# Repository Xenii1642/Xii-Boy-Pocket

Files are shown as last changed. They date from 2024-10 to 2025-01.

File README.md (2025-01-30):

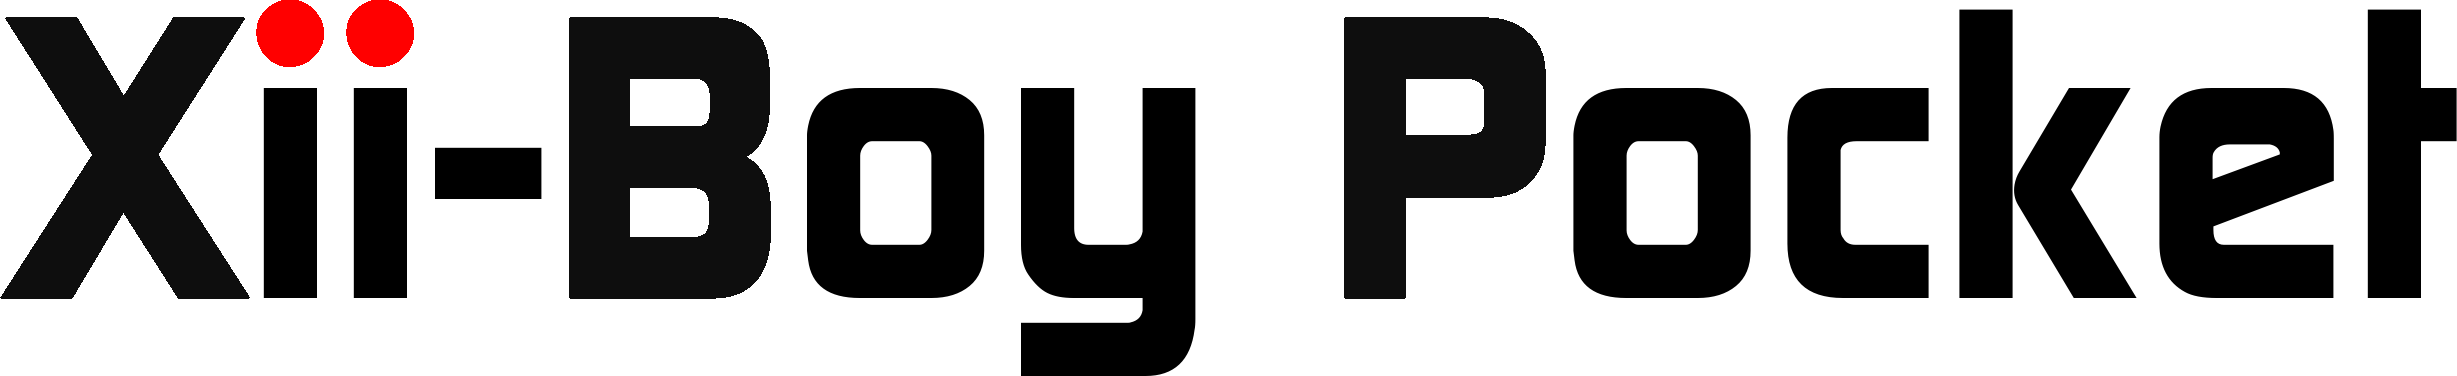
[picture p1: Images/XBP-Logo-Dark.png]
<picture> <source media="(prefers-color-scheme: dark)" srcset="Images/XBP-Logo-Light.png" width="800">  </picture> 

The Xii-Boy Pocket is a small portable Wii using a Game Boy form factor. The Xii-Boy Pocket is the second version of my Xii-Boy design.
This new portable Wii is now better, thinner, and above all, Open-Source ! Compared to the Gboy Rev III, it is 25% smaller and 5mm thinner !

If you want to learn more about it, you can check this BitBuilt Thread: [Xii-Boy Pocket's Thread](https://bitbuilt.net/forums/index.php?threads/the-xii-boy-pocket-v2.6638/)

If you want to see its development, you can check this BitBuilt Worklog: [Xii-Boy Pocket's Worklog](https://bitbuilt.net/forums/index.php?threads/xii-boy-v2-xeniis-second-portable-wii.6374/)

You can also learn more about the Xii-Boy Original here: [Xii-Boy Original Thread](https://bitbuilt.net/forums/index.php?threads/the-xii-boy-xeniis-first-portable-wii.6327/)

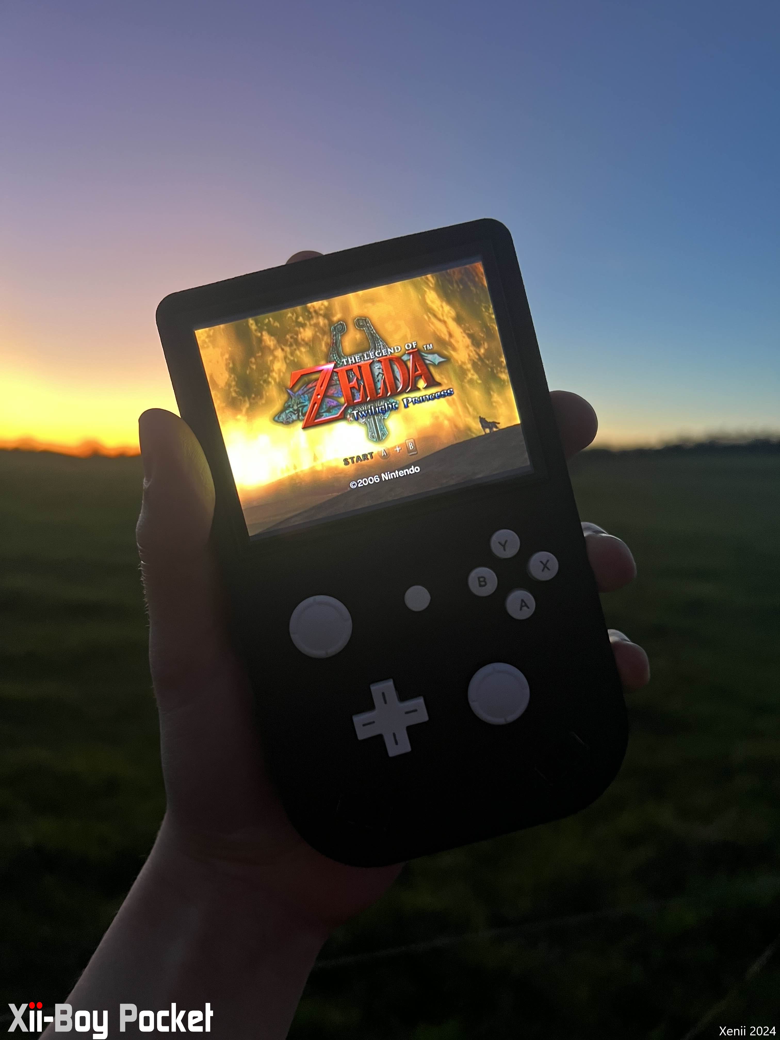
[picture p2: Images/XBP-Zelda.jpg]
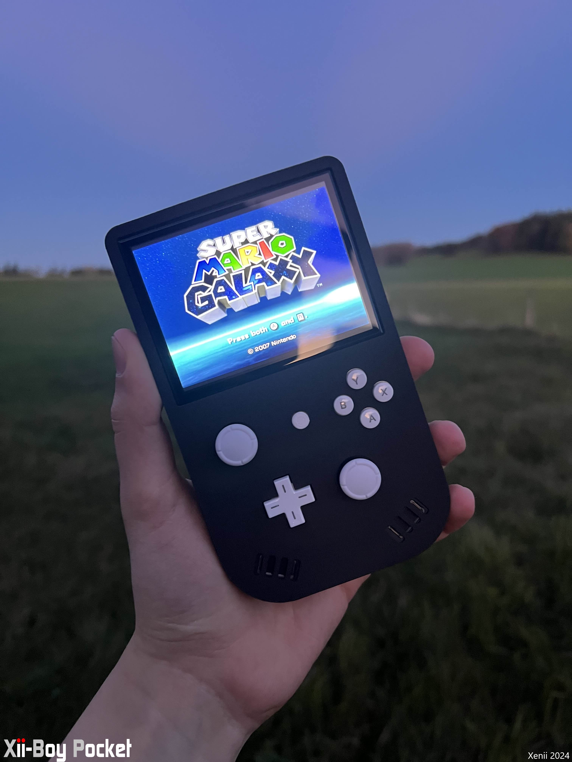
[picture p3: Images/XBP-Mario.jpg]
 
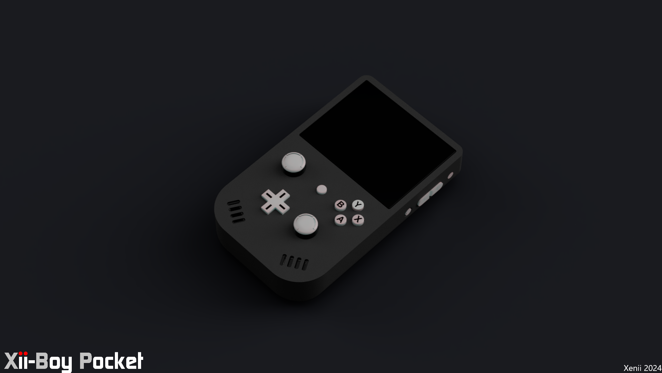
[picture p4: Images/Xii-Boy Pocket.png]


If you have any questions or problems about the Xii-Boy Pocket, please let me know 😉 Enjoy !

# Parts
All the parts you need to assemble a Xii-Boy Pocket are listed in the [Xii-Boy V2 Parts List.pdf](https://github.com/Xenii1642/Xii-Boy-Pocket/blob/main/Xii-Boy%20V2%20Parts%20List.pdf) file.

⚠ NOTE ⚠ For the batteries, I personally order mine through [Akkuteile](https://akkuteile.de/). However, if you don't live in Europe, you should buy your batteries somewhere else.
You just have to order two 18650 batteries. You shouldn't order them through Aliexpress, they could be fake and maybe dangerous

# PCB
All the Gerbers you need for the Xii-Boy Pocket are available in the [Gerber](https://github.com/Xenii1642/Xii-Boy-Pocket/tree/main/PCB%20Files/Gerber) folder.

All the needed components are listed in the [Xii-Boy V2 PCB BOM.pdf](https://github.com/Xenii1642/Xii-Boy-Pocket/blob/main/Xii-Boy%20V2%20PCB%20BOM.pdf) file.

The Xii-Boy Pocket's PCBs need specific settings to work properly:

### **Controller PCB**:
- ENIG surface finish 
  
### **Xii-Flex**:
- 0.12mm thickness
- Stiffener Polyimide 0.2 mm
  
### **Main PCB**:
- Impedance Controll YES
- Impedance Controll profile JLC04161H-7628

The other PCBs don't need specific settings. You can just let the setting by default 👍

I personally ordered mine through [JLCPCB](https://jlcpcb.com/) 👍

# Case
All the needed STLs are available in the [STL](https://github.com/Xenii1642/Xii-Boy-Pocket/tree/main/STL) folder.
If you want to order your case in **nylon** or **resin** through [JLC3DP](https://jlc3dp.com/), please use the case available in the [Case (JLC)](https://github.com/Xenii1642/Xii-Boy-Pocket/tree/main/STL/Case%20(JLC)) folder.

Otherwise, if you want to print / order it in FDM, use the case available in the [Case (FDM)](https://github.com/Xenii1642/Xii-Boy-Pocket/tree/main/STL/Case%20(FDM)) folder.

⚠️ Some of the buttons and fixations are too small to be manufactured by JLC3DP. To fix that, you can find a file which contains all the too small pieces [here](https://github.com/Xenii1642/Xii-Boy-Pocket/blob/main/STL/Buttons/Buttons-JLC.stl) ⚠️

I personally ordered my case through [JLC3DP](https://jlc3dp.com/) in **nylon SLS** and I printed the buttons in PLA 👍

⚠ NOTE ⚠ JLC3DP may ask you that there are some risks that the case could have warping or cracks. You have to accept them 👍

# STEP Files
You would like to make an edit on the case? No worries! You can find STEP files of the case in the [STEP folder](https://github.com/Xenii1642/Xii-Boy-Pocket/tree/main/STEP)

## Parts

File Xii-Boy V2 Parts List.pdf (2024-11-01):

Xii-Boy Pocket (V2) parts list

Parts | Quantity Link | Note

Controller
NDS Buttons | 1 https://www.aliexpress.com/item/1005006461579748.html | Buying NDS buttons and membranes from Aliexpress isn't the best choice.
NDS Membranes | 1 https://www.aliexpress.com/item/32832416623.html | If you can, you should take these from an original Nintendo DSi. The paint and the feeling will be better.
Switch Joysticks | 2 https://www.aliexpress.com/item/1005005499536700.html
Rumble Motor | 1 https://www.aliexpress.com/item/1005005616241057.html

Screen
Laminated 480p Screen | 1 https://www.aliexpress.com/item/1005006520627978.html | Select "With Black Cover"
480p Screen Driver Board | 1 https://www.aliexpress.com/item/1005003185913683.html | Select "HDMI Board"
Heatsink | | Select 50x100mm / 1mm 1pc
Fan | 1 https://www.aliexpress.com/item/4000313538245.html | Take "5V Balls 2PIN"
Heatsink | 1 https://www.aliexpress.com/item/1005005873687771.html
Copper Plate | 1 https://www.aliexpress.com/item/1005005993796912.html | Select 50x100mm / 1mm 1pc

Other
Batteries | 2 https://www.akkuteile.de/samsung-inr18650-35e-3-6v-3-7v-3500mah-pluspol-flach_100631_3391 If you don't live in Europe, you should buy your batteries somehwere else.
FFC Cables | 2 https://www.aliexpress.com/item/1005006653312883.html | You need 1x [60mm, Type A, 7P] and 1x [150, Type B, 10P]
Screews M1.7x4 | 39 https://www.aliexpress.com/item/33043885403.html | Select M1.7, 4mm, pan head
Screews M1.7x6 | 6 https://www.aliexpress.com/item/33043885403.html | Select M1.7 ,6mm, pan head
Speakers | 2 https://www.aliexpress.com/item/1005005931890295.html

PCB
LZ / RZ PCB | 1 https://github.com/Xenii1642/Xii-Boy-Pocket/tree/main/Gerber/RL-PCB
R / L PCB | 1 https://github.com/Xenii1642/Xii-Boy-Pocket/tree/main/Gerber/RL-PCB
Controller PCB | 1 https://github.com/Xenii1642/Xii-Boy-Pocket/tree/main/Gerber/Controller-PCB
Xii-Flex | 1 https://github.com/Xenii1642/Xii-Boy-Pocket/tree/main/Gerber/RL-PCB
Main PCB | 1 https://github.com/Xenii1642/Xii-Boy-Pocket/tree/main/Gerber/Main-PCB
RVL-PMS | 1 https://github.com/Gmanmodz/RVL-Power-Management-System

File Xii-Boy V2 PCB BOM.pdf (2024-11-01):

Xii-Boy V2 PCB BOM

LZ / RZ PCB
Reference | Quantity Description | Manufacter Product Number | Link
B1, B2 | 2 SWITCH TACTILE SPST-NO 0.05A 15V | TL3315NF250Q | https://www.digikey.com/en/products/detail/e-switch/TL3315NF250Q/1870396

L / R PCB
Reference | Quantity Description | Manufacter Product Number | Link
B1, B2 | 2 Dual Tact Button | TMHF07 | https://www.aliexpress.com/item/33003093225.html
P1 | 1 CONN FFC BOTTOM 7POS 0.5MM R/A | 5051100792 | https://www.digikey.com/en/products/detail/molex/5051100792/5700455

Controller PCB
Reference | Quantity Description | Manufacter Product Number | Link
B1 | 1 SWITCH TACTILE SPST-NO 0.05A 15V | TL3315NF250Q | https://www.digikey.com/en/products/detail/e-switch/TL3315NF250Q/1870396
C1, C2, C3 | 3 CAP CER 0.1UF 16V X7R 0402 | GRM155R71C104KA88J | https://www.digikey.com/en/products/detail/murata-electronics/GRM155R71C104KA88J/2610892
D1 | 1 DIODE ARR SCHOTT 20V TO236AB | PMEG2005CT,215 | https://www.digikey.com/en/products/detail/nexperia-usa-inc/PMEG2005CT-215/2119859
P1 | 1 CONN FFC BOTTOM 10POS 0.5MM R/A | 5051101092 | https://www.digikey.com/en/products/detail/molex/5051101092/5700458
P2 | 1 CONN FFC BOTTOM 7POS 0.5MM R/A | 5051100792 | https://www.digikey.com/en/products/detail/molex/5051100792/5700455
P3, P4 | 2 CONN FFC BOTTOM 5POS 0.5MM R/A | 5051100592 | https://www.digikey.com/en/products/detail/molex/5051100592/5700453
R1, R2 | 2 RES 10K OHM 5% 1/16W 0402 | RC0402JR-0710KL | https://www.digikey.com/en/products/detail/yageo/RC0402JR-0710KL/726418
R3 | 1 RES 100 OHM 1% 1/16W 0402 | RC0402FR-07100RL | https://www.digikey.com/en/products/detail/yageo/RC0402FR-07100RL/726527
U1 | 1 IC MCU 8BIT 32KB FLASH 28QFN | PIC18F25K42T-I/ML | https://www.digikey.com/en/products/detail/microchip-technology/PIC18F25K42T-I-ML/6685387
U2 | 1 IC MOTOR DRIVER 2.5V-5.2V 10QFN | DRV2603RUNR | https://www.digikey.com/en/products/detail/texas-instruments/DRV2603RUNR/3487230

Main PCB
Reference | Quantity Description | Manufacter Product Number | Link
B1, B2, B3, B4 | 4 SWITCH TACTILE SPST-NO 0.05A 12V | TL3336AF160Q | https://www.digikey.com/en/products/detail/e-switch/TL3336AF160Q/14123602
C1, C2, C3, C12, C15 | 5 CAP CER 1UF 6.3V X5R 0402 | CL05A105MQ5NNNC | https://www.digikey.com/en/products/detail/samsung-electro-mechanics/CL05A105MQ5NNNC/3886893
C4 | 1 CAP CER 10UF 6.3V X5R 0402 | GRM155R60J106ME05D | https://www.digikey.com/en/products/detail/murata-electronics/GRM155R60J106ME05D/11500166
C5, C6, C7, C8, C9, C10, C11 | 7 CAP CER 2.2UF 6.3V X5R 0402 | CL05A225MQ5NNNC | https://www.digikey.com/en/products/detail/samsung-electro-mechanics/CL05A225MQ5NNNC/3887127
C13, C14 | 2 CAP CER 4.7UF 6.3V X5R 0402 | GRM155R60J475ME87J | https://www.digikey.com/en/products/detail/murata-electronics/GRM155R60J475ME87J/9867919
LED1 | 1 LED RGB 0606 SMD | B38G3RGB-10D0003H2U1930 | https://www.digikey.com/en/products/detail/harvatek-corporation/B38G3RGB-10D0003H2U1930/13588733
P1 | 1 CONN RCPT TYPE C 6P SMD RA | USB4125-GF-A | https://www.digikey.com/en/products/detail/gct/USB4125-GF-A/13547388
P2 | 1 CONN FFC BOTTOM 10POS 0.5MM R/A | 5051101092 | https://www.digikey.com/en/products/detail/molex/5051101092/5700458
P3 | 1 MICRO SD PUSH/PUSH SMALL 8C | 5033981892 | https://www.digikey.com/en/products/detail/molex/5033981892/4555393
P4 | 1 CONN FFC BOTTOM 17POS 0.5MM R/A | 5051101792 | https://www.digikey.com/en/products/detail/molex/5051101792/5700465
P5 | 1 CONN RCPT 16POS SMD GOLD | 541020164 | https://www.digikey.com/en/products/detail/molex/0541020164/3197036
P6 | 1 CONN RCPT 20POS SMD GOLD | 529910208 | https://www.digikey.com/en/products/detail/molex/0529910208/1059850
P7 | 1 CONN JACK STEREO 3.5MM SMD R/A | SJ-3524-SMT-TR | https://www.digikey.com/en/products/detail/cui-devices/SJ-3524-SMT-TR/281298
R1, R2, R4 | 3 RES 10K OHM 5% 1/16W 0402 | RC0402JR-0710KL | https://www.digikey.com/en/products/detail/yageo/RC0402JR-0710KL/726418
R3 | 1 RES 24K OHM 1% 1/16W 0402 | WR04X2402FTL | https://www.digikey.com/en/products/detail/walsin-technology-corporation/WR04X2402FTL/16569971
R5 | 1 RES 1K OHM 1% 1/16W 0402 | WR04X1001FTL | https://www.digikey.com/en/products/detail/walsin-technology-corporation/WR04X1001FTL/13240628
U1 | 1 IC MCU 8BIT 7KB FLASH 16UQFN | PIC16LF15324-I/JQ | https://www.digikey.com/en/products/detail/microchip-technology/PIC16LF15324-I-JQ/6691288
U2 | 1 IC REG LINEAR 2.5V 250MA SOT23-5 | LP5907MFX-2.5/NOPB | https://www.digikey.com/en/products/detail/texas-instruments/LP5907MFX-2-5-NOPB/5019039
U3 | 1 IC AMP CLASS D STER 2.5W 32WQFN | LM49450SQ/NOPB | https://www.digikey.com/en/products/detail/texas-instruments/LM49450SQ-NOPB/1871761
U4 | 1 CH224K USB PD Protocol Sink Chip IC | CH224K | https://www.aliexpress.com/item/1005005284290184.html
U5 | 1 GL823K GL823 SSOP-16 | GL823K | https://www.aliexpress.com/item/1005007494983714.html

RVL-PMS (Gman)
Reference | Quantity Description | Manufacter Product Number | Link
U1 U2 U3 U4 | 4 IC REG BUCK ADJUSTABLE 4A 16VQFN | TLV62095RGTR | https://www.digikey.com/product-detail/en/texas-instruments/TLV62095RGTR/296-46277-1-ND/7033452
U5 | 1 IC REG BOOST 5V 4A 10VSON | TPS61232DRCR | https://www.digikey.com/product-detail/en/texas-instruments/TPS61232DRCR/296-44498-1-ND/6110782
U6 | 1 IC MCU 8BIT 7KB FLASH 16UQFN | PIC16F15324T-I/JQ | https://www.digikey.com/product-detail/en/microchip-technology/PIC16F15324T-I-JQ/PIC16F15324T-I-JQCT-ND/7346310
U7 | 1 IC NVDC CHARGER I2C 24WQFN | BQ25895MRTWR | https://www.digikey.com/en/products/detail/texas-instruments/BQ25895MRTWR/5413643
R1 | 1 RES SMD 44.2K OHM 1% 1/10W 0603 | RC0603FR-0744K2L | https://www.digikey.com/product-detail/en/yageo/RC0603FR-0744K2L/311-44.2KHRCT-ND/730188
R2 R4 R6 R8 | 4 RES SMD 160K OHM 1% 1/10W 0603 | RC0603FR-07160KL | https://www.digikey.com/product-detail/en/yageo/RC0603FR-07160KL/311-160KHRCT-ND/729920
R3 | 1 RES SMD 75K OHM 1% 1/10W 0603 | RC0603FR-0775KL | https://www.digikey.com/product-detail/en/yageo/RC0603FR-0775KL/311-75.0KHRCT-ND/730325
R5 | 1 RES SMD 200K OHM 1% 1/10W 0603 | RC0603FR-07200KL | https://www.digikey.com/product-detail/en/yageo/RC0603FR-07200KL/311-200KHRCT-ND/729991
R7 | 1 RES SMD 510K OHM 1% 1/10W 0603 | RC0603FR-07510KL | https://www.digikey.com/product-detail/en/yageo/RC0603FR-07510KL/311-510KHRCT-ND/730233
R9 R10 R11 | 3 RES 1.2K OHM 1% 1/10W 0603 | RMCF0603FT1K20 | https://www.digikey.com/product-detail/en/stackpole-electronics-inc/RMCF0603FT1K20/RMCF0603FT1K20CT-ND/1942999
R12 R13 R17 R18 | 4 RES SMD 10K OHM 1% 1/10W 0603 | RC0603FR-0710KL | https://www.digikey.com/product-detail/en/yageo/RC0603FR-0710KL/311-10.0KHRCT-ND/729827
R14 | 1 RES SMD 261 OHM 1% 1/10W 0603 | RC0603FR-07261RL | https://www.digikey.com/product-detail/en/yageo/RC0603FR-07261RL/311-261HRCT-ND/730042
R15 R16 | 2 RES SMD 4.7K OHM 1% 1/10W 0603 | RC0603FR-074K7L | https://www.digikey.com/product-detail/en/yageo/RC0603FR-074K7L/311-4.70KHRCT-ND/730159
C1 C3 C5 C7 C9 C10 C11 C12 C13, C14,
C15, C16, C17, C18, C19, C20
C14 C15 C16 C17 C18 C19 C20 | 16 CAP CER 22UF 6.3V X5R 0805 | CL21A226MQQNNNE | https://www.digikey.com/product-detail/en/samsung-electro-mechanics/CL21A226MQQNNNE/1276-1100-1-ND/3889186
C2 C4 C6 C8 | 4 CAP CER 10000PF 50V X7R 0603 | 06035C103KAT4A | https://www.digikey.com/product-detail/en/avx-corporation/06035C103KAT4A/478-10055-1-ND/6564278
C21 | 1 CAP CER 1UF 25V X7R 0805 | GCM21BR71E105KA56L | https://www.digikey.com/product-detail/en/murata-electronics-north-america/GCM21BR71E105KA56L/490-4785-1-ND/1641704
C22 | 1 CAP CER 0.1UF 25V X5R 0603 | CL10A104KA8NNNC | https://www.digikey.com/product-detail/en/samsung-electro-mechanics/CL10A104KA8NNNC/1276-1857-1-ND/3889943
C23 | 1 CAP CER 0.047UF 25V X7R 0603 | C0603C473K3RACTU | https://www.digikey.com/product-detail/en/kemet/C0603C473K3RACTU/399-7931-1-ND/3471654
C24 C26 C27 C28 | 4 CAP CER 10UF 16V X5R 0805 | CL21A106KOQNNNG | https://www.digikey.com/product-detail/en/samsung-electro-mechanics/CL21A106KOQNNNG/1276-6455-1-ND/5958083
C25 | 1 CAP CER 4.7UF 16V X5R 0603 | CL10A475KO8NNNC | https://www.digikey.com/product-detail/en/samsung-electro-mechanics/CL10A475KO8NNNC/1276-1784-1-ND/3889870
L1 L2 L3 L4 L5 | 5 FIXED IND 1UH 5.1A 27 MOHM SMD | MDWK4040T1R0MM | https://www.digikey.com/product-detail/en/taiyo-yuden/MDWK4040T1R0MM/587-4447-1-ND/5880037
L6 | 1 FIXED IND 2.2UH 8A 20 MOHM SMD | ASPI-0630HI-2R2M-T15 | https://www.digikey.com/product-detail/en/abracon-llc/ASPI-0630HI-2R2M-T15/ASPI-0630HI-2R2M-T15CT-ND/3060148

Screen Driver Board
Reference | Quantity Description | Manufacter Product Number | Link
Crystal (Y1) | 1 CRYSTAL 27.0000MHZ 8PF SMD | LNCD1-27M | https://www.digikey.com/en/products/detail/ndk-america-inc/LNCD1-27M/1128824
Inductor (L14) | 1 FIXED IND 22UH 450MA 910MOHM SMD | 74404024220 | https://www.digikey.com/en/products/detail/w%C3%BCrth-elektronik/74404024220/4865382

Other
Name | Quantity Description | Manufacter Product Number | Link
Wifi Antenna | 2 RF ANT 2.45GHZ PCB TRACE CAB ADH | ANTX100P011B24003 | https://www.digikey.com/en/products/detail/pulse-electronics/ANTX100P011B24003/9360397
Battery Clips | 4 BATT CONT SPR MULTI SOLDER LUG | 1107-1 | https://www.digikey.com/en/products/detail/keystone-electronics/1107-1/5056817
Thermistor | 1 THERMISTOR NTC 10KOHM 3470K BEAD | MF52A2103J3470 | https://www.digikey.com/en/products/detail/cantherm/MF52A2103J3470/1191033
Light Pipe | 1 LIGHT PIPE PNL 3MM DFF FLAT.100" | PLP1-100-FD | https://www.digikey.com/en/products/detail/bivar-inc/PLP1-100-F-D/5721997

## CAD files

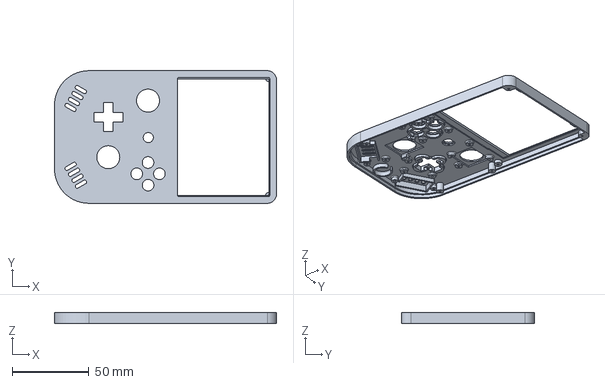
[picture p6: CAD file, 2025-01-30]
STEP/JLC/Xii-Boy Pocket Top (JLC).step
145.0 x 86.7 x 7.50 mm

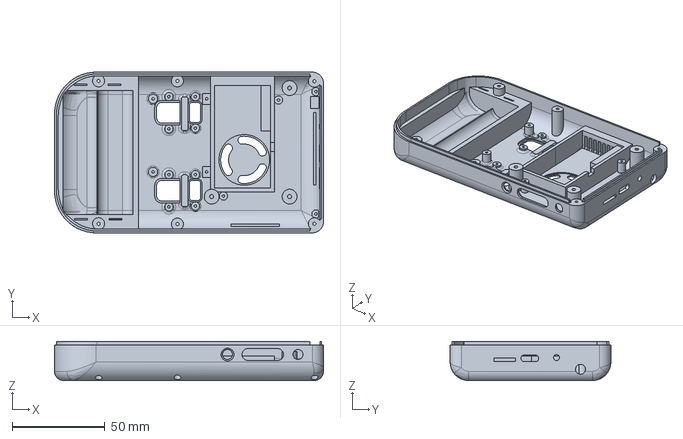
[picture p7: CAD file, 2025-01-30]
STEP/Xii-Boy Pocket Bottom.step
145.0 x 86.6 x 21.1 mm

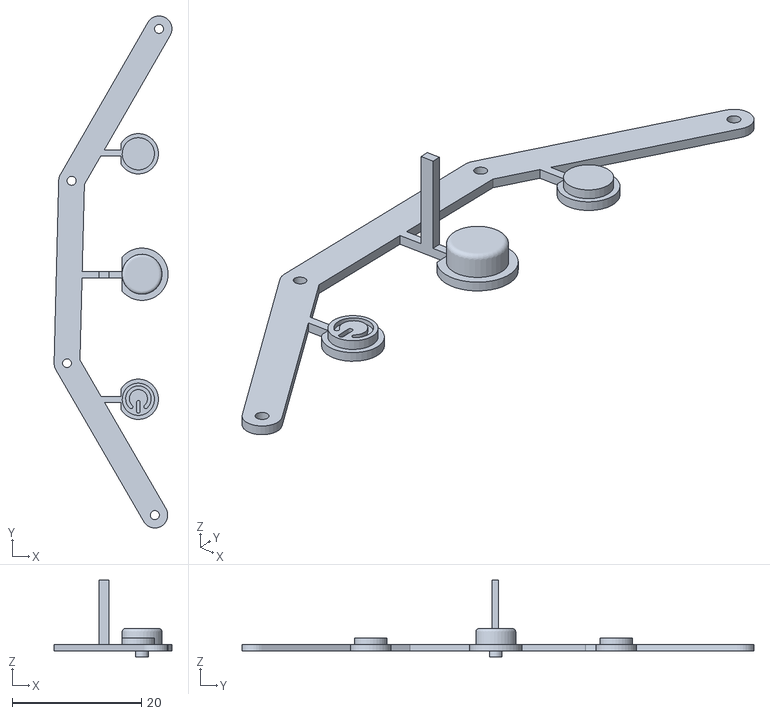
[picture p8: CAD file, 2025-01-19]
STL/Buttons/Buttons-JLC.stl
18.2 x 79.3 x 11.9

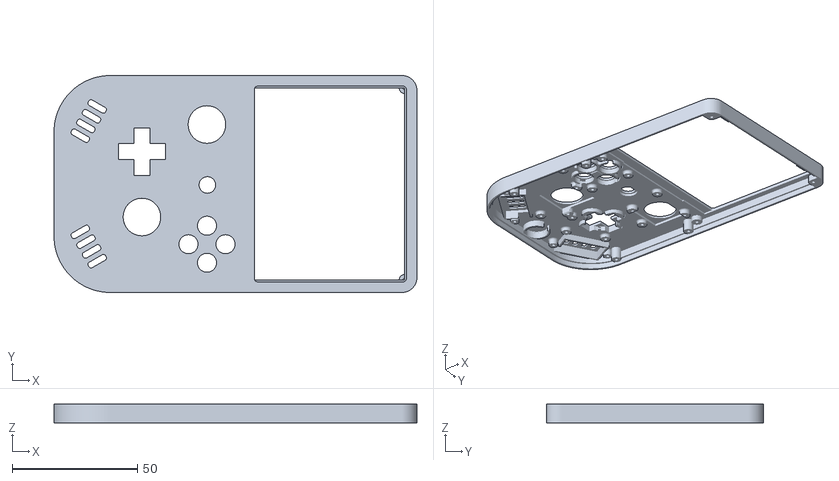
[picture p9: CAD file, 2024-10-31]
STL/Case (FDM)/Xii-Boy Top.stl
145.0 x 86.6 x 7.50

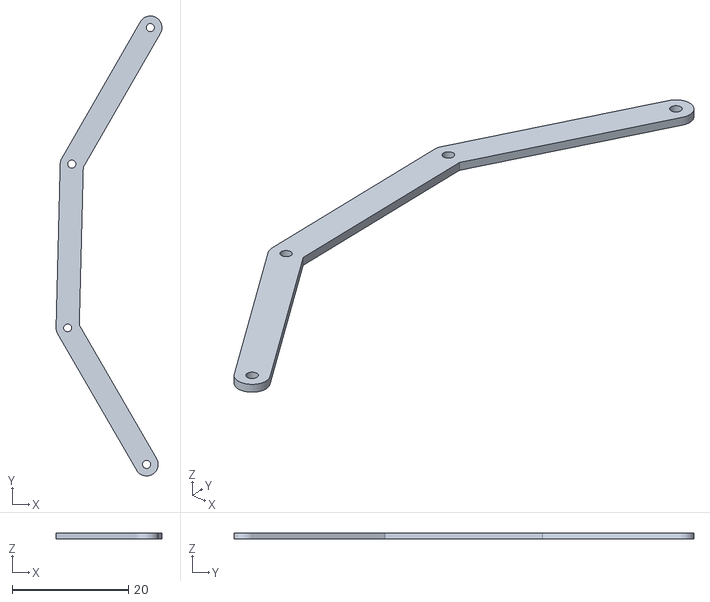
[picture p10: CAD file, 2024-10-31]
STL/Fixations/Speakers + Rumble.stl
18.3 x 79.3 x 1.00

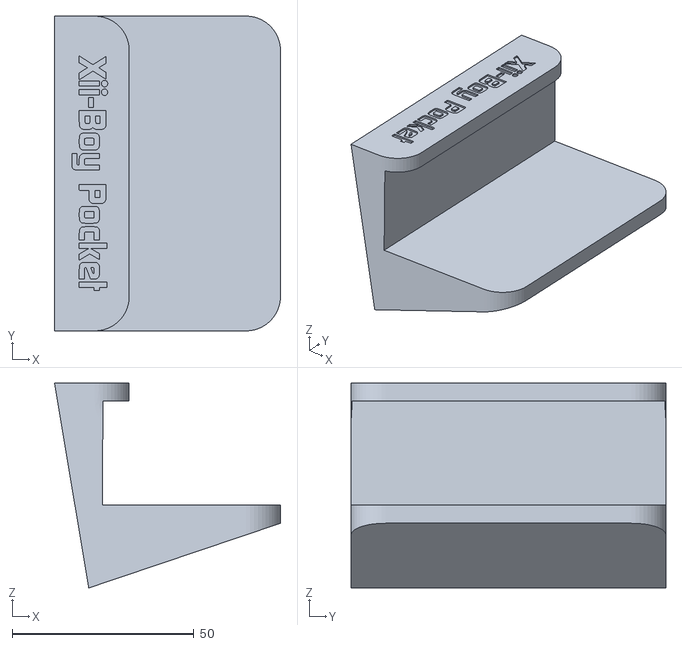
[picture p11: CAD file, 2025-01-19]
STL/Xii-Boy Pocket Stand (without XiiSBar).stl
62.2 x 86.6 x 56.4

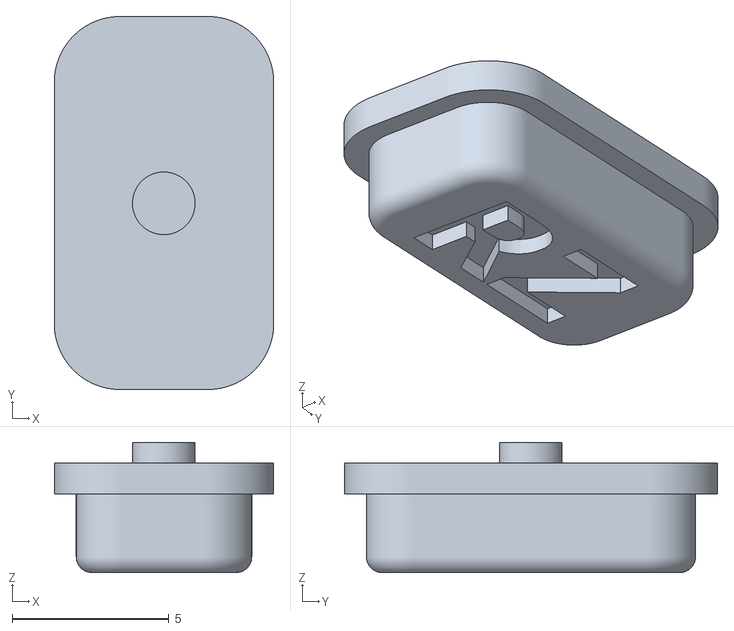
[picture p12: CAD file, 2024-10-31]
STL/Buttons/RZ.stl
7.00 x 11.9 x 4.15

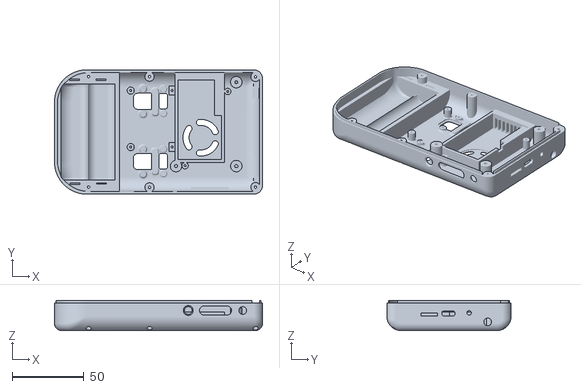
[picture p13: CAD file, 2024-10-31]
STL/Case (FDM)/Xii-Boy Bottom.stl
145.0 x 86.6 x 21.1

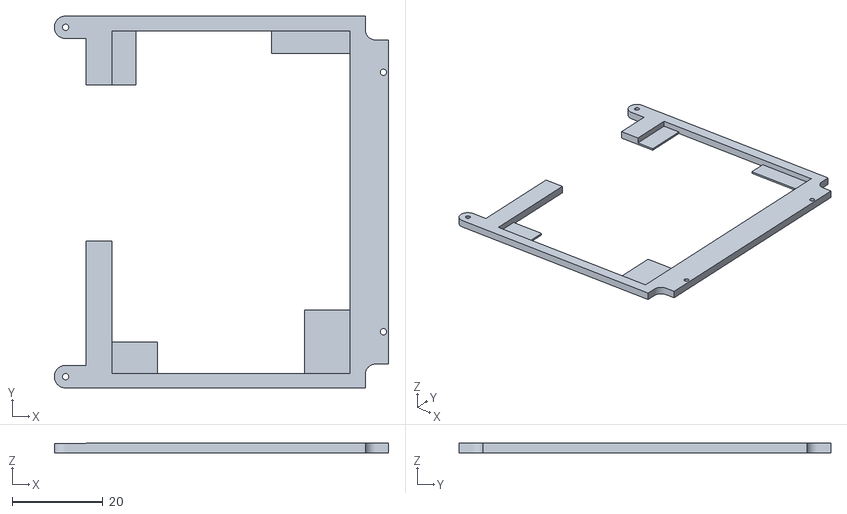
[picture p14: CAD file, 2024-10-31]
STL/Fixations/Driver Board.stl
73.9 x 82.2 x 2.10

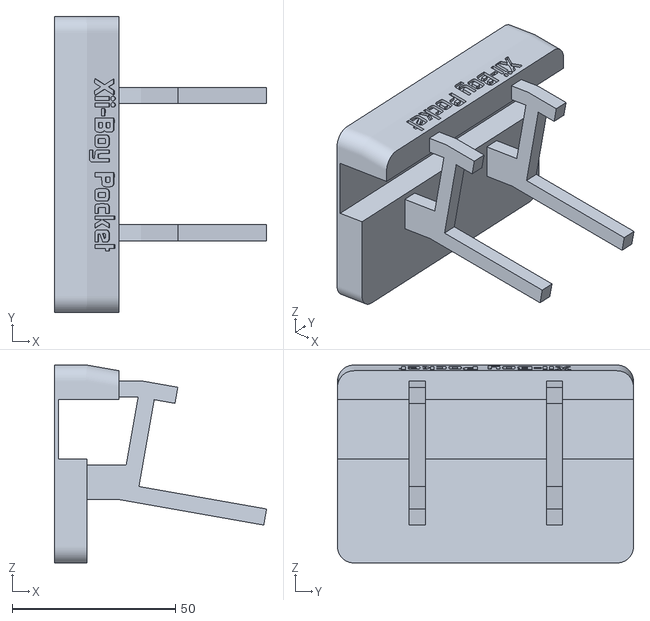
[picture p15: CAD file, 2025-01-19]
STL/Xii-Boy Pocket Stand.stl
65.0 x 90.6 x 60.6

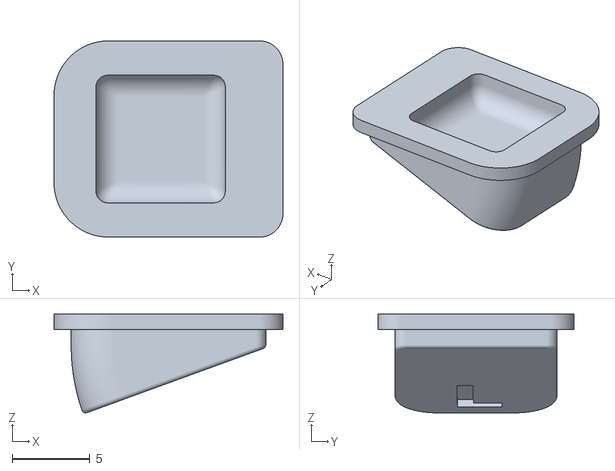
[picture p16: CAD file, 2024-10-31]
STL/Buttons/L.stl
14.7 x 12.6 x 6.34

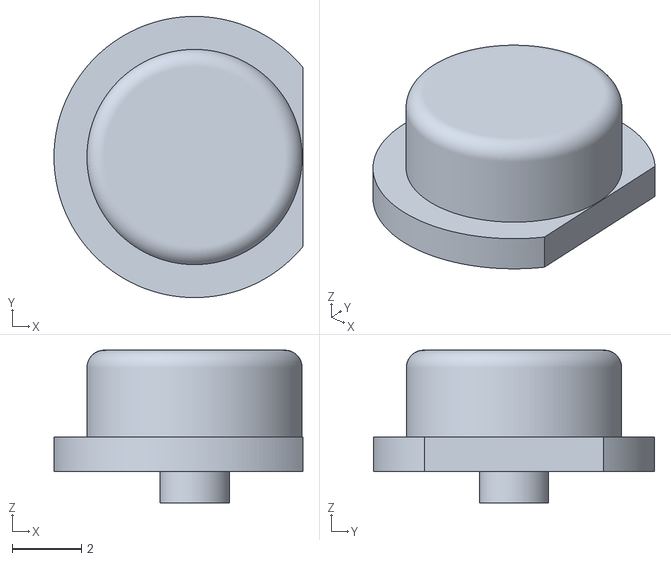
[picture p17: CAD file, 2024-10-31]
STL/Buttons/Start.stl
7.17 x 8.10 x 4.40

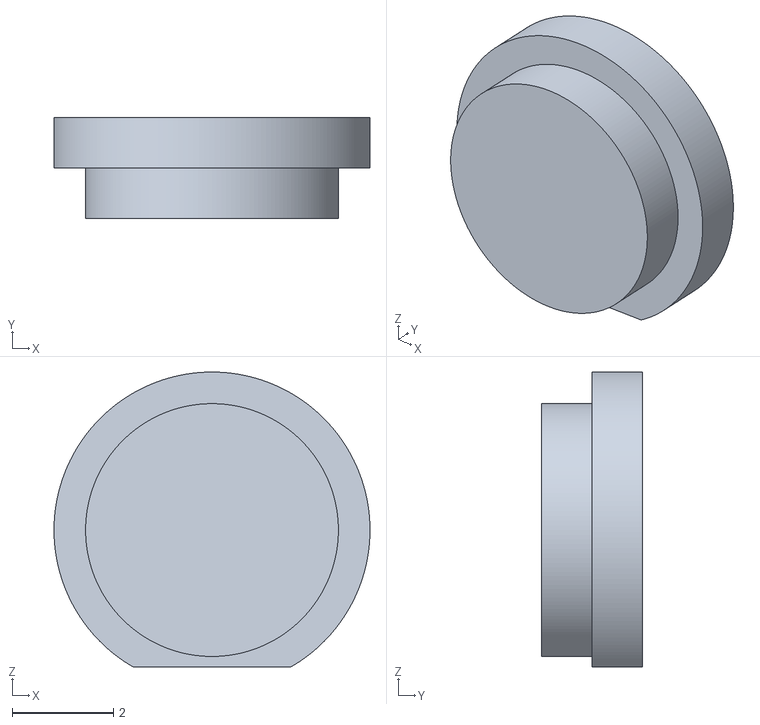
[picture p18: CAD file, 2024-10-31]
STL/Buttons/Sync.stl
6.25 x 2.00 x 5.83

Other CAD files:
STL/Case (JLC)/Xii-Boy Top (JLC).stl
STEP/JLC/Xii-Boy Pocket Bottom (JLC).step
STEP/Xii-Boy Pocket Top.step
STL/Case (JLC)/Xii-Boy Bottom (JLC).stl
STL/Buttons/LZ.stl
STL/Buttons/Power.stl
STL/Buttons/R.stl
STL/Buttons/Volume.stl

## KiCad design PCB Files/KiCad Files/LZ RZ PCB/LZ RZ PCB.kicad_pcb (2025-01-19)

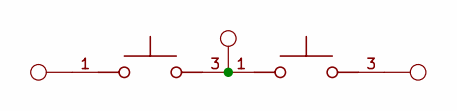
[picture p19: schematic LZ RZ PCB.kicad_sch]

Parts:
S1, S2: TL3315NF250Q; SW_TL3315NF250Q
TP1: LZ; TestPoint_Pad_D1.0mm
TP2: GND; TestPoint_Pad_D1.0mm
TP3: RZ; TestPoint_Pad_D1.0mm

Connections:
unnamed: S1.1, TP1.1
unnamed: S1.3, S2.1, TP2.1
unnamed: S2.3, TP3.1

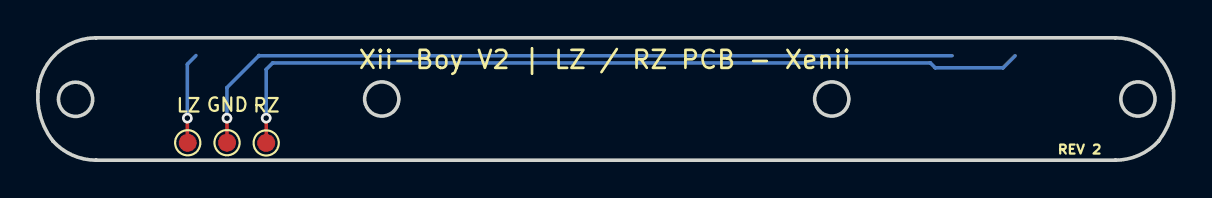
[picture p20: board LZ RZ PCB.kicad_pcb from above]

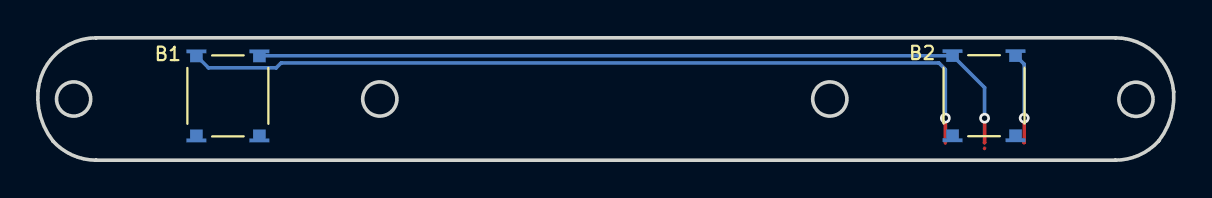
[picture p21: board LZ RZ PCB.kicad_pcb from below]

Board: 2 copper layers, 63.1 x 6.8 mm, 5 parts (2 on the bottom side), 3 nets.

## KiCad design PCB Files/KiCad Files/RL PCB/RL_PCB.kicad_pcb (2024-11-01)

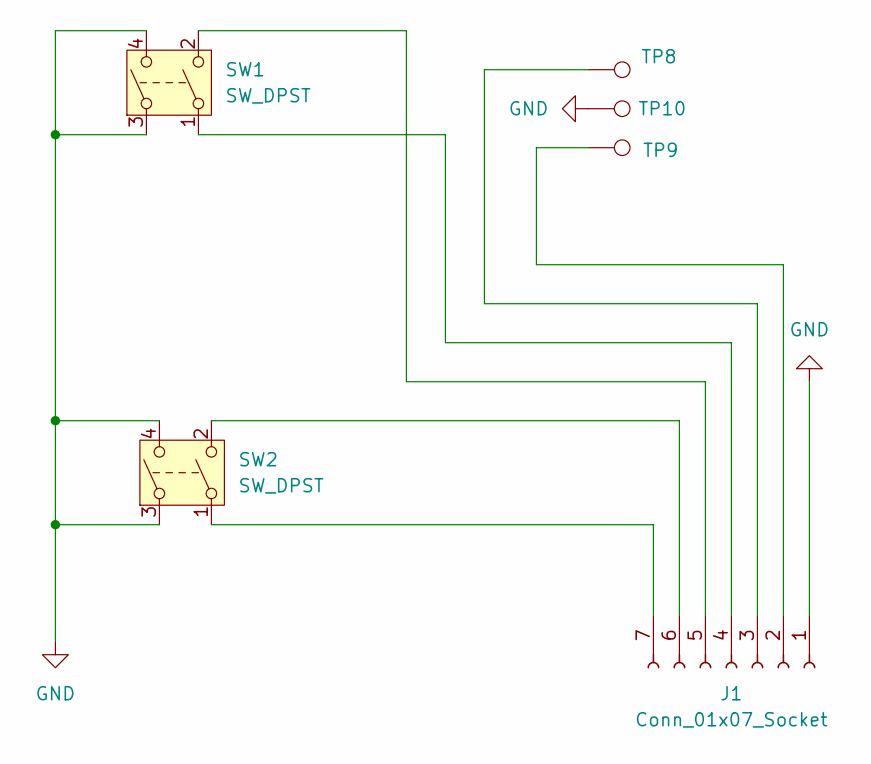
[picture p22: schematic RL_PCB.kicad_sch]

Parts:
J1: Conn_01x07_Socket; CON_5051100792_MOL
SW1, SW2: SW_DPST; TMHF07
TP8, TP9, TP10: TestPoint; TestPoint_Pad_D1.0mm

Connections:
GND: J1.1, SW1.3, SW1.4, SW2.3, SW2.4, TP10.1
unnamed: J1.2, TP9.1
unnamed: J1.3, TP8.1
unnamed: J1.4, SW1.1
unnamed: J1.5, SW1.2
unnamed: J1.6, SW2.2
unnamed: J1.7, SW2.1

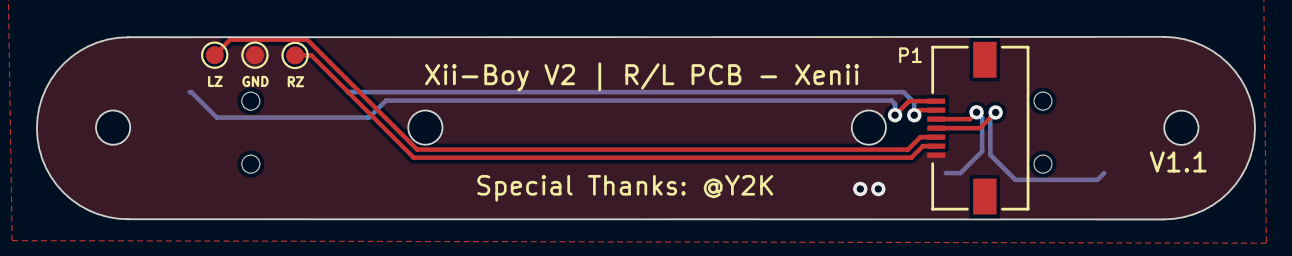
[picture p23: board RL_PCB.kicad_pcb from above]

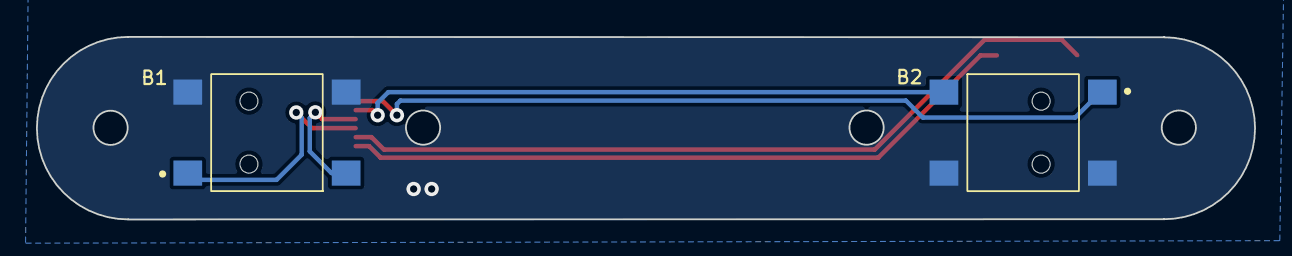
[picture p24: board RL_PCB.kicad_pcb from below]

Board: 2 copper layers, 67.7 x 10.1 mm, 6 parts (2 on the bottom side), 7 nets.

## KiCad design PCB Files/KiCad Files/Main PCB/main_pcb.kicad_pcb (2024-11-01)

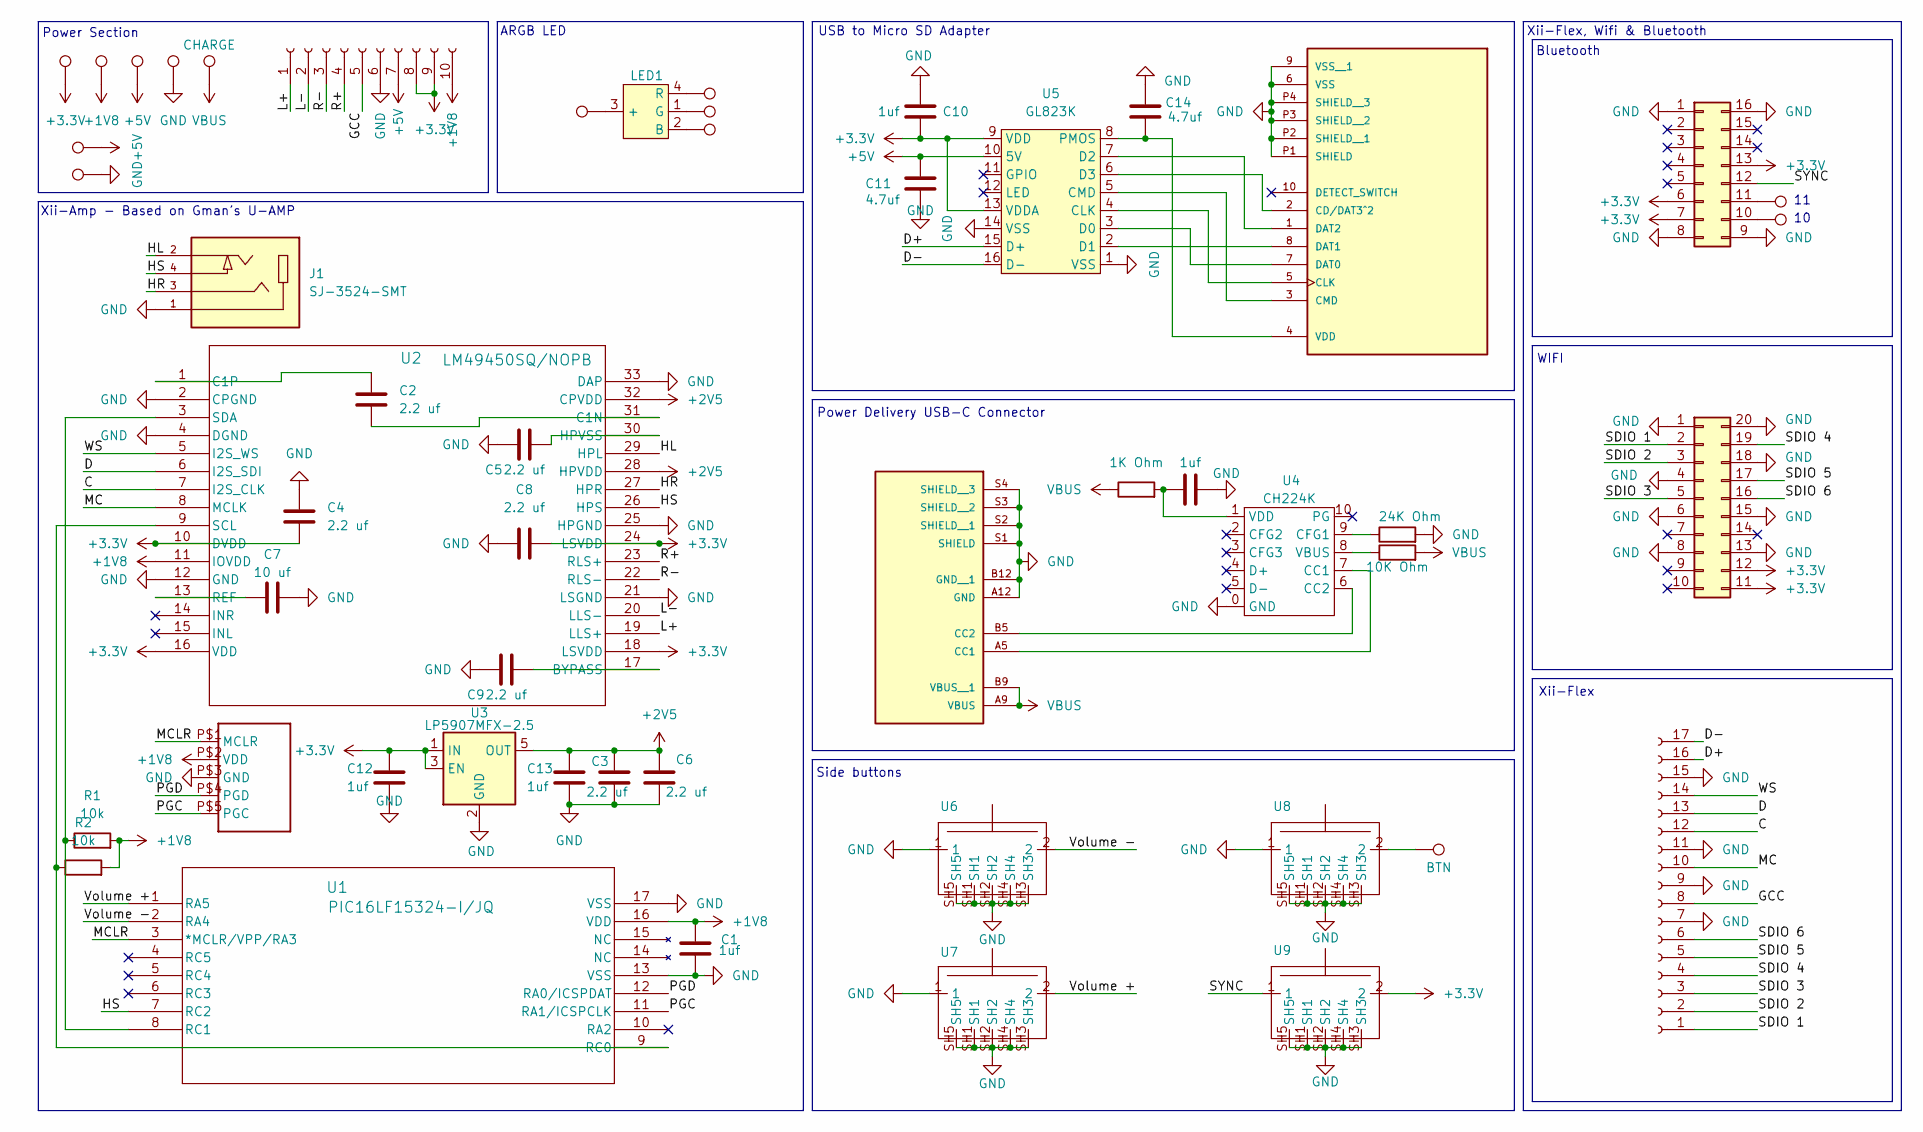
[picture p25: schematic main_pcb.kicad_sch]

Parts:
C1, C10, C12, C13, C15: 1uf; C_0402_1005Metric
C2, C3, C4, C5, C6, C8, C9: 2.2 uf; C_0402_1005Metric
C7: 10 uf; C_0402_1005Metric
C11, C14: 4.7uf; C_0402_1005Metric
J1: SJ-3524-SMT; CUI_SJ-3524-SMT; PARTREV 1.03
J2: USB4125-GF-A_REVA2; GCT_USB4125-GF-A_REVA2; PARTREV Rev A2
J3: 503398-1892; MOLEX_503398-1892; PARTREV 0
J4: Conn_01x10_Socket; CON_5051101092_MOL
J5: Conn_01x17_Socket; CON_5051101792_MOL
J6: Conn_02x08_Counter_Clockwise; CON_541020164
J7: Conn_02x10_Counter_Clockwise; CON_529910208
LED1: LED_B38G3RGB-10D0003H2U1930
PH1: GC+2_PROGRAMMING_HEADER; programmer
R1, R2: 10k; R_0402_1005Metric
R3: 1K Ohm; R_0402_1005Metric
R4: 24K Ohm; R_0402_1005Metric
R5: 10K Ohm; R_0402_1005Metric
TP1, TP2, TP3, TP6, TP7, TP8: TestPoint; Xenii-Voltage-Pad
TP4, TP5, TP10, TP11, TP12, TP13: TestPoint; TestPoint_Pad_D1.0mm
TP9: CHARGE; Xenii-Voltage-Pad
TP14: BTN; TestPoint_Pad_D1.0mm
U1: PIC16LF15324-I/JQ; U-Amp_pic
U2: LM49450SQ/NOPB; U-Amp LM49450SQ
U3: LP5907MFX-2.5; SOT-23-5
U4: CH224K; ESSOP-10
U5: GL823K; SSOP-16_3.9x4.9mm_P0.635mm
U6, U7, U8, U9: SW_TL3336AF160Q

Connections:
+1V8: C1.1, J4.10, PH1.P$2 (VDD), R1.2, R2.2, TP2.1, U1.16 (VDD), U2.11 (IOVDD)
+2V5: C3.2, C6.2, C13.1, U2.28 (HPVDD), U2.32 (CPVDD), U3.5 (OUT)
+3.3V: C4.2, C8.2, C10.2, C12.1, J4.8, J4.9, J6.6, J6.7, J6.13, J7.11, J7.12, TP1.1, U2.10 (DVDD), U2.16 (VDD), U2.18 (LSVDD), U2.24 (LSVDD), U3.1 (IN), U3.3 (EN), U5.9 (VDD), U5.13 (VDDA), U9.2
+5V: C11.1, J4.7, TP3.1, TP6.1, U5.10 (5V)
/C: J5.12, U2.7 (I2S_CLK)
/D: J5.13, U2.6 (I2S_SDI)
/D+: J5.16, U5.15 (D+)
/D-: J5.17, U5.16 (D-)
/GCC: J4.5, J5.8
/HL: J1.2, U2.29 (HPL)
/HR: J1.3, U2.27 (HPR)
/HS: J1.4, U1.7 (RC2), U2.26 (HPS)
/L+: J4.1, U2.19 (LLS+)
/L-: J4.2, U2.20 (LLS-)
/MC: J5.10, U2.8 (MCLK)
/MCLR: PH1.P$1 (MCLR), U1.3 (*MCLR/VPP/RA3)
/PGC: PH1.P$5 (PGC), U1.11 (RA1/ICSPCLK)
/PGD: PH1.P$4 (PGD), U1.12 (RA0/ICSPDAT)
/R+: J4.4, U2.23 (RLS+)
/R-: J4.3, U2.22 (RLS-)
/SDIO 1: J5.1, J7.2
/SDIO 2: J5.2, J7.3
/SDIO 3: J5.3, J7.5
/SDIO 4: J5.4, J7.19
/SDIO 5: J5.5, J7.17
/SDIO 6: J5.6, J7.16
/SYNC: J6.12, U9.1
/Volume +: U1.1 (RA5), U7.2
/Volume -: U1.2 (RA4), U6.2
/WS: J5.14, U2.5 (I2S_WS)
GND: C1.2, C3.1, C4.1, C5.1, C6.1, C7.2, C8.1, C9.1, C10.1, C11.2, C12.2, C13.2, C14.2, C15.2, J1.1, J2.A12 (GND), J2.B12 (GND__1), J2.S1 (SHIELD), J2.S2 (SHIELD__1), J2.S3 (SHIELD__2), J2.S4 (SHIELD__3), J3.6 (VSS), J3.9 (VSS__1), J3.P1 (SHIELD), J3.P2 (SHIELD__1), J3.P3 (SHIELD__2), J3.P4 (SHIELD__3), J4.6, J5.7, J5.9, J5.11, J5.15, J6.1, J6.8, J6.9, J6.16, J7.1, J7.4, J7.6, J7.8, J7.13, J7.15, J7.18, J7.20, PH1.P$3 (GND), R4.2, TP7.1, TP8.1, U1.13 (VSS), U1.17 (VSS), U2.2 (CPGND), U2.4 (DGND), U2.12 (GND), U2.21 (LSGND), U2.25 (HPGND), U2.33 (DAP), U3.2 (GND), U4.0 (GND), U5.1 (VSS), U5.14 (VSS), U6.1, U6.SH1, U6.SH2, U6.SH3, U6.SH4, U6.SH5, U7.1, U7.SH1, U7.SH2, U7.SH3, U7.SH4, U7.SH5, U8.1, U8.SH1, U8.SH2, U8.SH3, U8.SH4, U8.SH5, U9.SH1, U9.SH2, U9.SH3, U9.SH4, U9.SH5
unnamed: J2.A5 (CC1), U4.7 (CC1)
unnamed: J2.B5 (CC2), U4.6 (CC2)
unnamed: J3.2 (CD/DAT3^2), U5.6 (D3)
unnamed: J3.5 (CLK), U5.4 (CLK)
unnamed: J3.3 (CMD), U5.5 (CMD)
unnamed: J3.7 (DAT0), U5.3 (D0)
unnamed: J3.8 (DAT1), U5.2 (D1)
unnamed: J3.1 (DAT2), U5.7 (D2)
unnamed: C14.1, J3.4 (VDD), U5.8 (PMOS)
unnamed: J6.10, TP5.1
unnamed: J6.11, TP4.1
unnamed: LED1.3 (+), TP10.1
unnamed: LED1.2 (B), TP13.1
unnamed: LED1.1 (G), TP12.1
unnamed: LED1.4 (R), TP11.1
unnamed: TP14.1, U8.2
unnamed: R2.1, U1.9 (RC0), U2.9 (SCL)
unnamed: R1.1, U1.8 (RC1), U2.3 (SDA)
unnamed: C9.2, U2.17 (BYPASS)
unnamed: C2.2, U2.31 (C1N)
unnamed: C2.1, U2.1 (C1P)
unnamed: C5.2, U2.30 (HPVSS)
unnamed: C7.1, U2.13 (REF)
unnamed: R4.1, U4.9 (CFG1)
unnamed: R5.1, U4.8 (VBUS)
unnamed: C15.1, R3.2, U4.1 (VDD)
VBUS: J2.A9 (VBUS), J2.B9 (VBUS__1), R3.1, R5.2, TP9.1

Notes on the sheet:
Xii-Amp - Based on Gman's U-AMP
Xii-Flex
Xii-Flex, Wifi & Bluetooth
Power Section
WIFI
Bluetooth
Side buttons
ARGB LED
Power Delivery USB-C Connector
USB to Micro SD Adapter

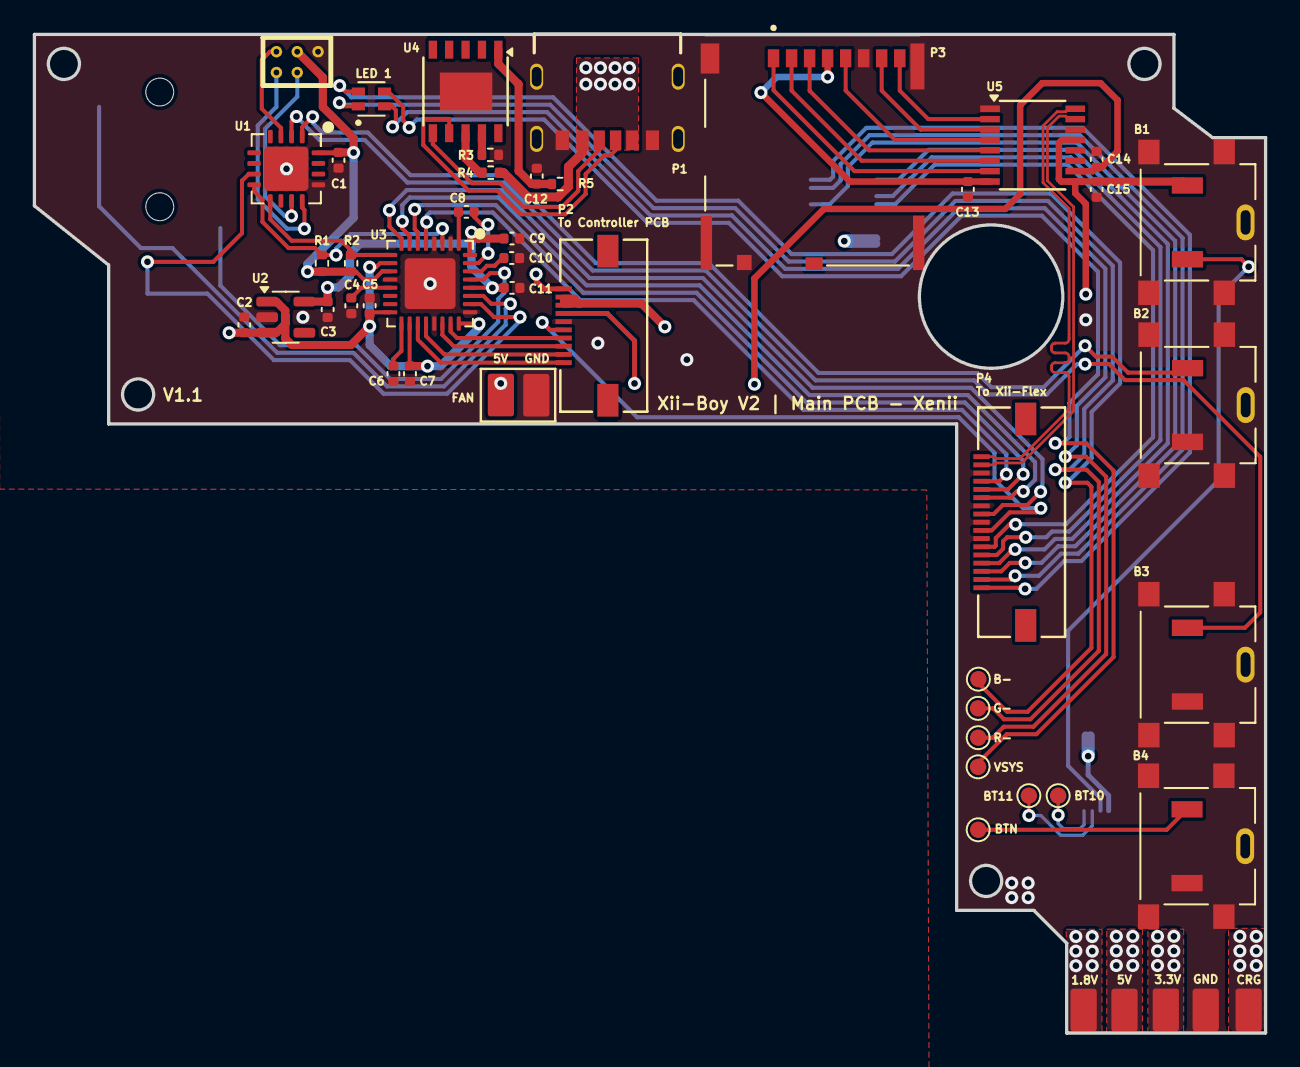
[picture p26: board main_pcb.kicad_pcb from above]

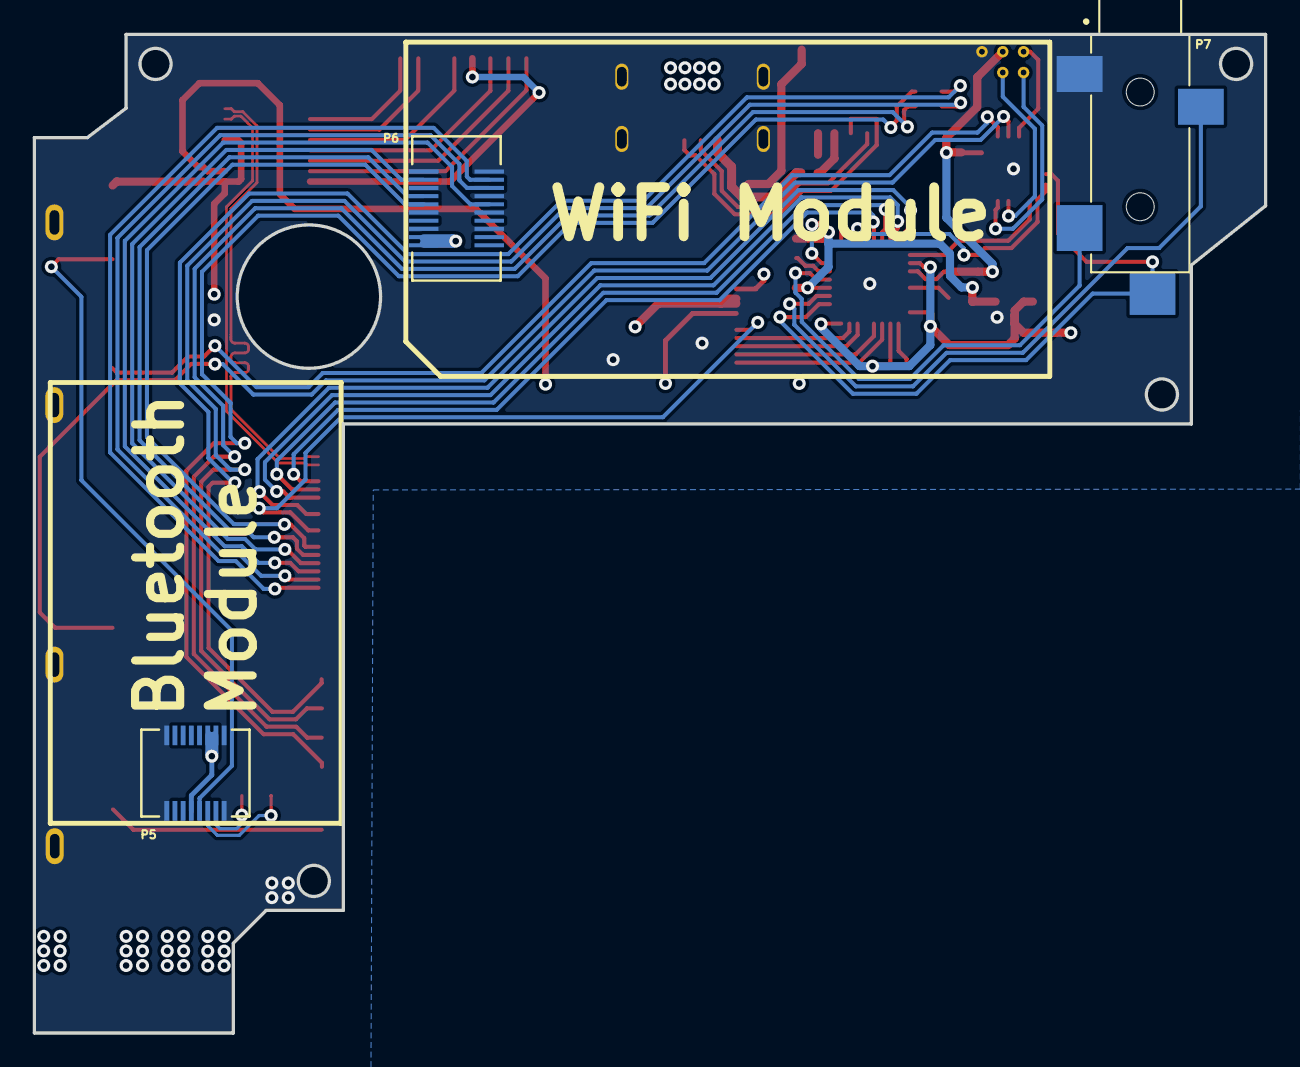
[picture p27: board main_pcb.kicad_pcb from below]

Board: 4 copper layers, 75.1 x 60.9 mm, 52 parts (3 on the bottom side), 58 nets.

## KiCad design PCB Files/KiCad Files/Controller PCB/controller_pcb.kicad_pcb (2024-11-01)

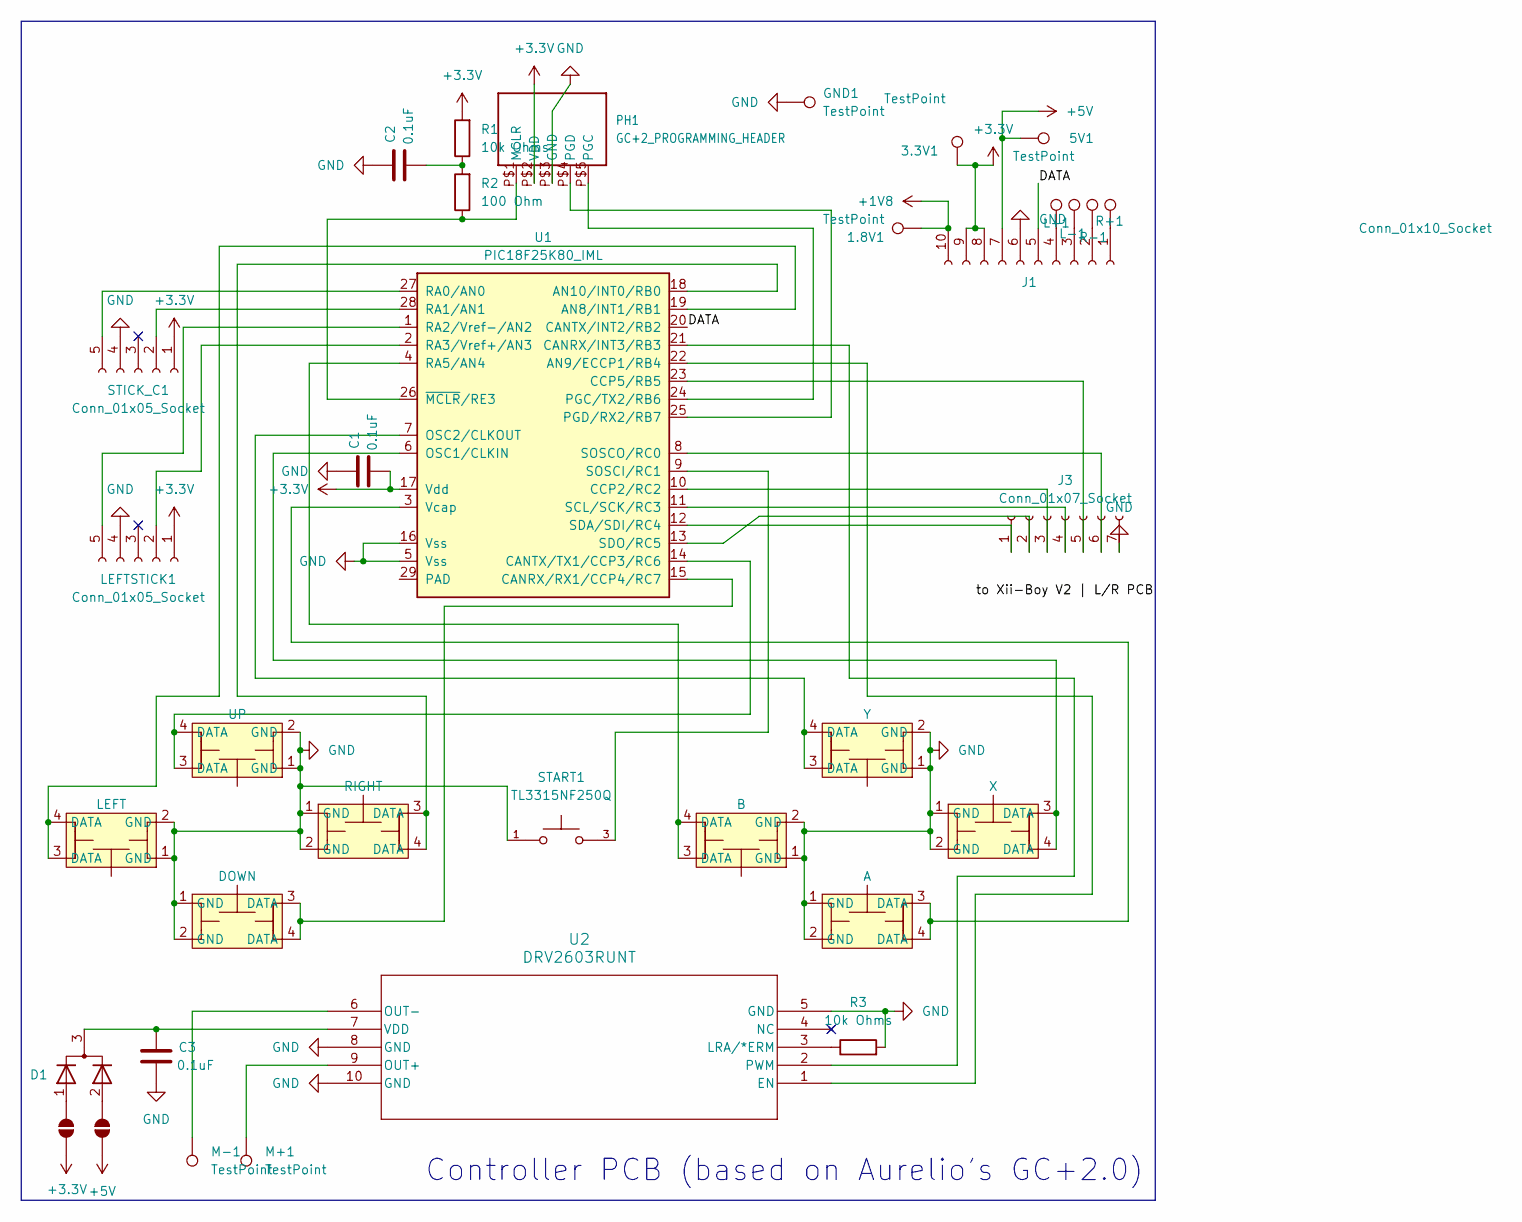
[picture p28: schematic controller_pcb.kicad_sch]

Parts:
1.8V1, 3.3V1, 5V1: TestPoint; TestPoint_Pad_D1.0mm
C1, C2, C3: 0.1uF; C_0402_1005Metric
D1: D_Dual_CommonCathode_AAK_Parallel; SOT_05CT215_NEX-L
DSL_Pad1: LEFT; DSL_Pad
DSL_Pad2: UP; DSL_Pad
DSL_Pad3: DOWN; DSL_Pad
DSL_Pad4: RIGHT; DSL_Pad
DSL_Pad5: B; DSL_Pad
DSL_Pad6: Y; DSL_Pad
DSL_Pad7: A; DSL_Pad
DSL_Pad8: X; DSL_Pad
GND1: TestPoint; TestPoint_Pad_D1.0mm
J1: Conn_01x10_Socket; CON_5051101092_MOL
J3: Conn_01x07_Socket; CON_5051100792_MOL
JP1, JP2: SolderJumper_2_Open; SolderJumper-2_P1.3mm_Open_RoundedPad1.0x1.5mm
L+1: TestPoint; TestPoint_Pad_D1.0mm
L-1: TestPoint; TestPoint_Pad_D1.0mm
LEFTSTICK1: Conn_01x05_Socket; CON_5051100592_MOL
M+1: TestPoint; TestPoint_Pad_D1.0mm
M-1: TestPoint; TestPoint_Pad_D1.0mm
PH1: GC+2_PROGRAMMING_HEADER; programmer
R1, R3: 10k Ohms; R_0402_1005Metric
R2: 100 Ohm; R_0402_1005Metric
R+1: TestPoint; TestPoint_Pad_D1.0mm
R-1: TestPoint; TestPoint_Pad_D1.0mm
START1: TL3315NF250Q; SW_TL3315NF250Q
STICK_C1: Conn_01x05_Socket; CON_5051100592_MOL
U1: PIC18F25K80_IML; PIC18F2542 (GC+ 2.0)
U2: DRV2603RUNT; RUN10_TEX

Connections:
+1V8: 1.8V1.1, J1.10
+3.3V: 3.3V1.1, C1.1, J1.8, J1.9, JP1.1 (A), LEFTSTICK1.1, PH1.P$2 (VDD), R1.2, STICK_C1.1, U1.17 (Vdd)
+5V: 5V1.1, J1.7, JP2.2 (B)
/DATA: J1.5, U1.20 (CANTX/INT2/RB2)
GND: C1.2, C2.2, C3.1, DSL_Pad1.1 (GND), DSL_Pad1.2 (GND), DSL_Pad2.1 (GND), DSL_Pad2.2 (GND), DSL_Pad3.1 (GND), DSL_Pad3.2 (GND), DSL_Pad4.1 (GND), DSL_Pad4.2 (GND), DSL_Pad5.1 (GND), DSL_Pad5.2 (GND), DSL_Pad6.1 (GND), DSL_Pad6.2 (GND), DSL_Pad7.1 (GND), DSL_Pad7.2 (GND), DSL_Pad8.1 (GND), DSL_Pad8.2 (GND), GND1.1, J1.6, J3.7, LEFTSTICK1.4, PH1.P$3 (GND), R3.2, START1.1, STICK_C1.4, U1.5 (Vss), U1.16 (Vss), U1.PAD, U2.5 (GND), U2.8 (GND), U2.10 (GND)
unnamed: C2.1, R1.1, R2.2
unnamed: C3.2, D1.3 (A), U2.7 (VDD)
unnamed: J1.1, R+1.1
unnamed: J1.2, R-1.1
unnamed: J1.3, L-1.1
unnamed: J1.4, L+1.1
unnamed: J3.1, U1.12 (SDA/SDI/RC4)
unnamed: J3.2, U1.13 (SDO/RC5)
unnamed: J3.3, U1.10 (CCP2/RC2)
unnamed: J3.4, U1.11 (SCL/SCK/RC3)
unnamed: J3.5, U1.23 (CCP5/RB5)
unnamed: J3.6, U1.8 (SOSCO/RC0)
unnamed: D1.1 (K), JP1.2 (B)
unnamed: D1.2 (K), JP2.1 (A)
unnamed: LEFTSTICK1.2, U1.2 (RA3/Vref+/AN3)
unnamed: LEFTSTICK1.5, U1.1 (RA2/Vref-/AN2)
unnamed: PH1.P$1 (MCLR), R2.1, U1.26 (~MCLR/RE3)
unnamed: PH1.P$5 (PGC), U1.24 (PGC/TX2/RB6)
unnamed: PH1.P$4 (PGD), U1.25 (PGD/RX2/RB7)
unnamed: STICK_C1.2, U1.28 (RA1/AN1)
unnamed: STICK_C1.5, U1.27 (RA0/AN0)
unnamed: DSL_Pad1.3 (DATA), DSL_Pad1.4 (DATA), U1.19 (AN8/INT1/RB1)
unnamed: U1.22 (AN9/ECCP1/RB4), U2.1 (EN)
unnamed: DSL_Pad4.3 (DATA), DSL_Pad4.4 (DATA), U1.18 (AN10/INT0/RB0)
unnamed: U1.21 (CANRX/INT3/RB3), U2.2 (PWM)
unnamed: DSL_Pad3.3 (DATA), DSL_Pad3.4 (DATA), U1.15 (CANRX/RX1/CCP4/RC7)
unnamed: DSL_Pad2.3 (DATA), DSL_Pad2.4 (DATA), U1.14 (CANTX/TX1/CCP3/RC6)
unnamed: DSL_Pad8.3 (DATA), DSL_Pad8.4 (DATA), U1.6 (OSC1/CLKIN)
unnamed: DSL_Pad6.3 (DATA), DSL_Pad6.4 (DATA), U1.7 (OSC2/CLKOUT)
unnamed: DSL_Pad5.3 (DATA), DSL_Pad5.4 (DATA), U1.4 (RA5/AN4)
unnamed: START1.3, U1.9 (SOSCI/RC1)
unnamed: DSL_Pad7.3 (DATA), DSL_Pad7.4 (DATA), U1.3 (Vcap)
unnamed: R3.1, U2.3 (LRA/*ERM)
unnamed: M+1.1, U2.9 (OUT+)
unnamed: M-1.1, U2.6 (OUT-)

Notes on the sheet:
Controller PCB (based on Aurelio's GC+2.0)

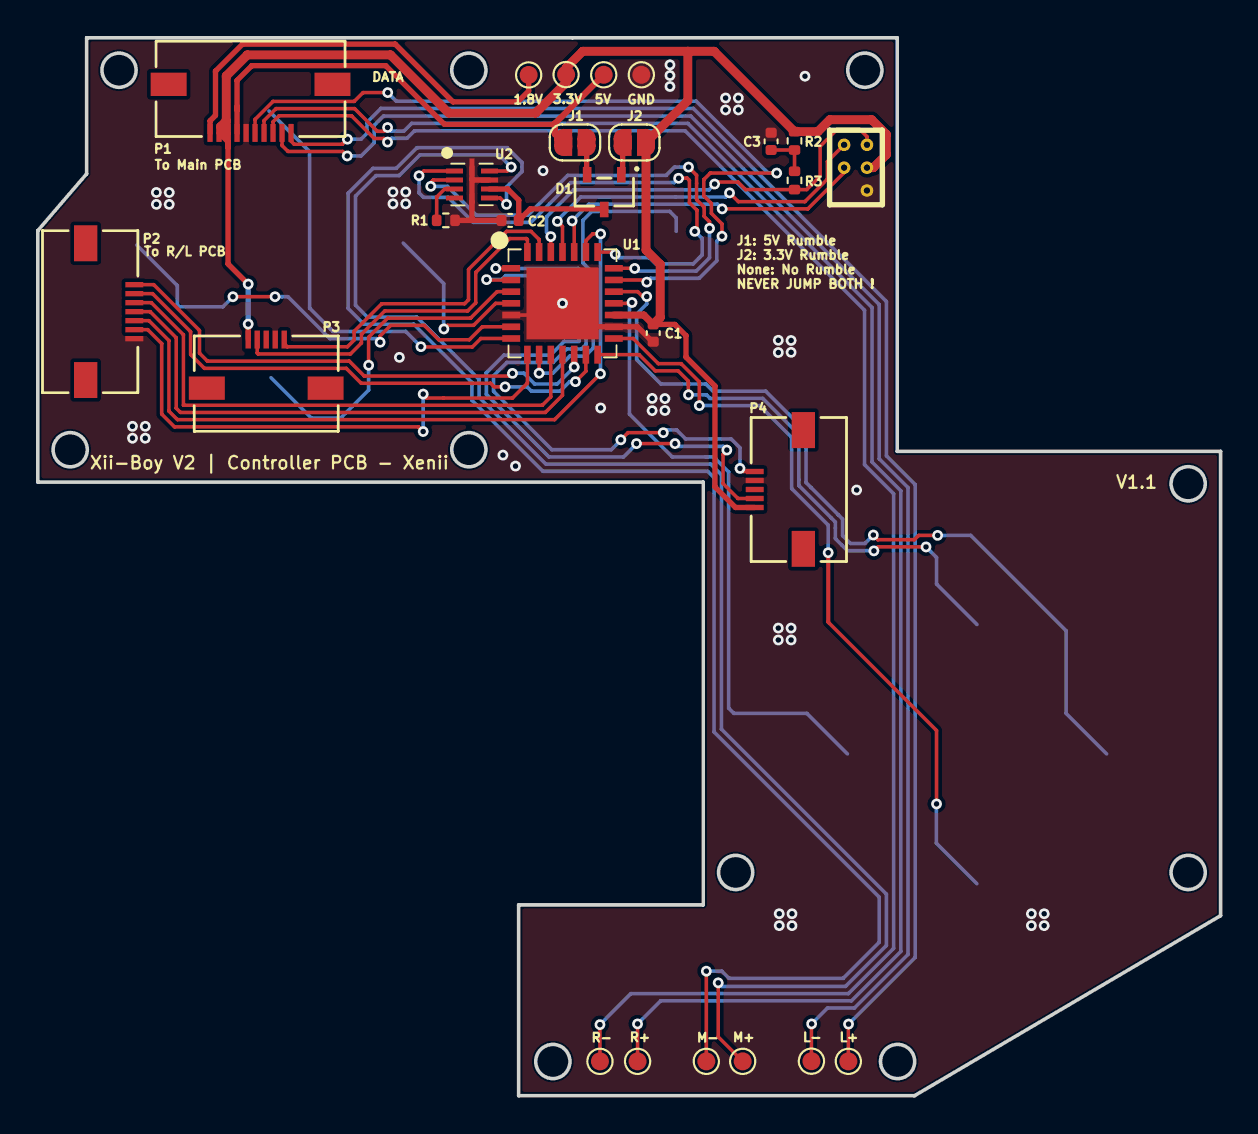
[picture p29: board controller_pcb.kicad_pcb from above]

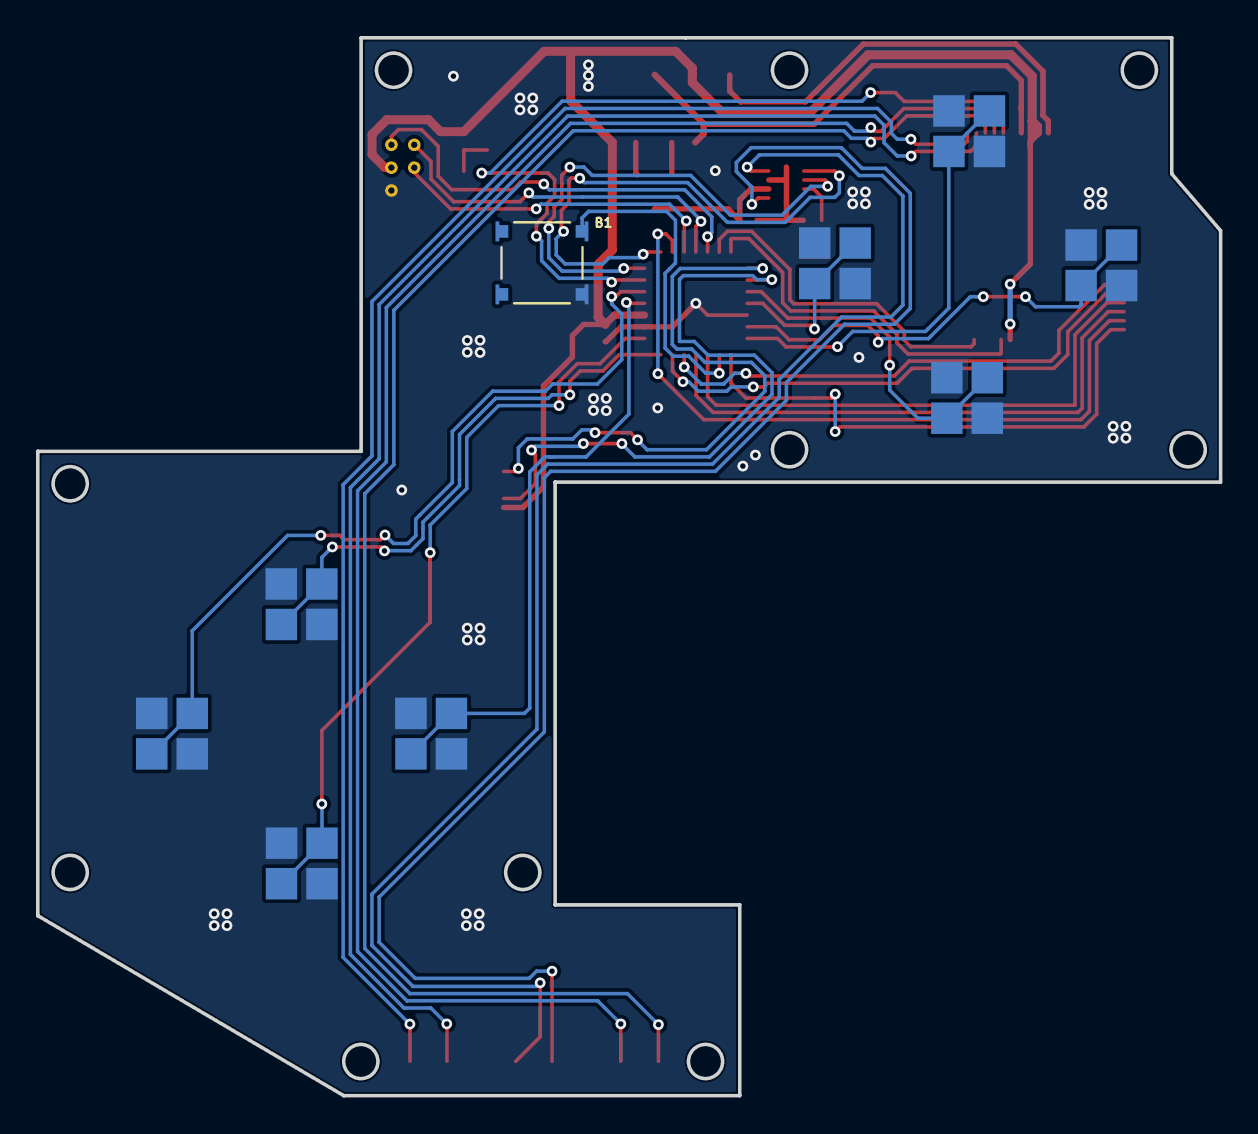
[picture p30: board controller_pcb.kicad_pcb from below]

Board: 2 copper layers, 65.7 x 58.8 mm, 35 parts (9 on the bottom side), 40 nets.

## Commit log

2025-01-19 New top case revision
    Upgrade the screen fitment.
    [Xii-Boy Top (JLC).stl]
2025-01-19 Button group for JLC
    This file contains all the too small buttons and group them.
    [Buttons-JLC.stl]
2025-01-19 Add Xii-Boy Pocket Stand (compatible with XiiSBar)
    [Xii-Boy Pocket Stand.stl]
2025-01-30 Add STEP files for limitless case edits!
    [Xii-Boy Pocket Bottom (JLC).step, Xii-Boy Pocket Bottom.step, Xii-Boy Pocket Top (JLC).step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]
